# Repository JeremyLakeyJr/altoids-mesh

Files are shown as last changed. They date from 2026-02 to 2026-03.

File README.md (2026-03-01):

# Altoids Mesh Enclosure

A parametric, 3D-printable enclosure modeled after an Altoids tin, designed to house a complete Meshtastic communication node.

## Preview

### Assembled View
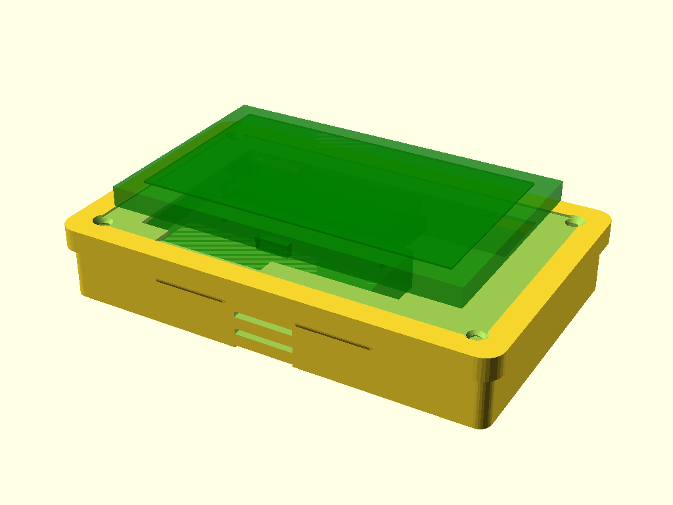
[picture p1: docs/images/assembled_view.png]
Assembled view of the Altoids Mesh enclosure


### Exploded View
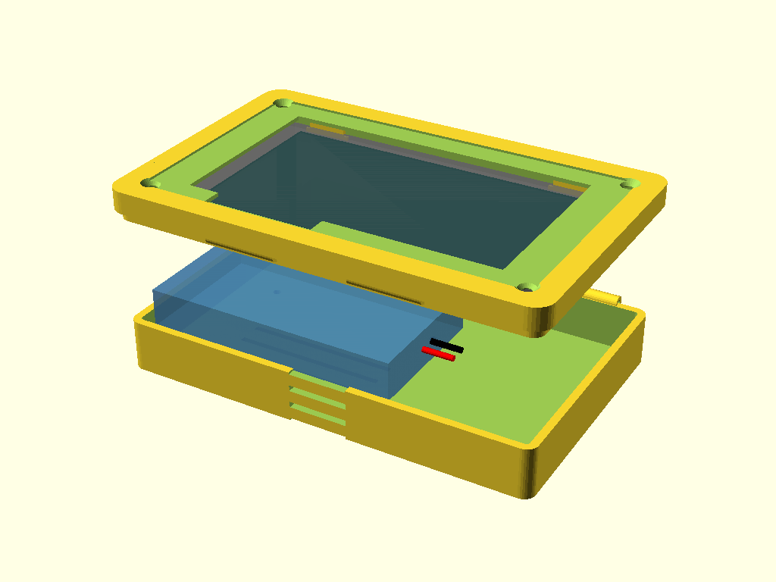
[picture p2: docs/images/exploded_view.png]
Exploded view showing all components separated


### Print Layout
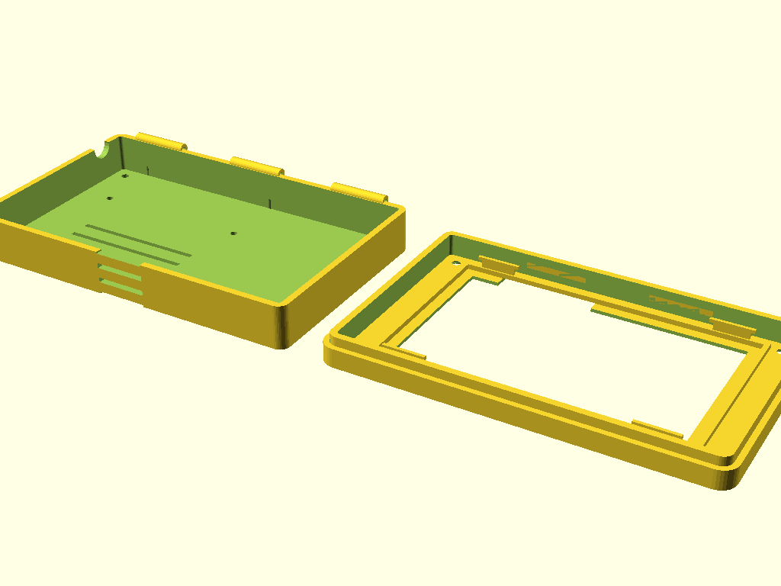
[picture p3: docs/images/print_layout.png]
Print layout with parts arranged for 3D printing


## Components

| Component | Dimensions (mm) | Description |
|---|---|---|
| Heltec V3 (WiFi LoRa 32) | 50.2 × 25.5 × 10.2 | ESP32-S3 + SX1262 LoRa module with OLED display (IPEX antenna) |
| Heltec V4 (WiFi LoRa 32) | 52 × 25 × 7 | Meshtastic-compatible LoRa module with OLED display |
| M5Stack CardKB Unit 1.1 | 88 × 54 × 5 | Credit-card-sized QWERTY keyboard (I2C) |
| MakerFocus 3.7V 3000mAh | 65 × 36 × 10 | Lithium polymer rechargeable battery |
| Standard paper clip | ~0.9 mm wire | Straightened — hinge pin for laptop-style lid |

## Enclosure Specifications

- **Style**: Altoids tin aesthetic — overlapping lid with embossed label panel
- **Wall thickness**: 2.0 mm case / 1.6 mm lid skirt (FDM-optimised)
- **Floor/ceiling**: 1.6 mm
- **Tolerance**: 0.3 mm general, 0.5 mm component fit
- **Closure**: Friction-fit overlapping lid with paper-clip barrel hinge
- **Hinge**: Barrel-type knuckle hinge along back edge — assembled with a straightened paper clip
- **Material**: PLA, PETG, or ABS recommended

## Key Design Features

- **Fully sealed when closed** — no through-holes, ports, or vents; all interfaces accessible when lid is hinged open
- **Altoids-style overlapping lid** — the lid skirt slides over the case walls, just like a real tin
- **Embossed label panel** — shallow recess on the lid top for branding or labelling
- **Front friction bump** — snap catch at the front for tool-free open/close
- **Paper-clip hinge** — no special hardware needed; a standard paper clip becomes the hinge pin
- **Battery compartment** with retention clips
- **Heltec V3 / V4 mounting** with M2 standoffs and PCB alignment guides
- **CardKB integration** in the lid with support ledges and retention clips
- **OLED display** visible when lid is open
- **Internal antenna housing** channel with retention clips — primary antenna solution (plastic doesn't block RF)
- **Corner screw bosses** for structural reinforcement

## File Structure

```
enclosure/
├── altoids_mesh_enclosure.scad   # Main assembly (open this first)
├── parameters.scad                # All configurable dimensions
├── components.scad                # Component models for visualisation
├── bottom_case.scad               # Bottom case (battery + Heltec)
└── top_lid.scad                   # Top lid (CardKB + display window)
docs/
├── assembly_guide.md              # Step-by-step assembly instructions
└── images/                        # Preview renders
stl/
└── .gitkeep                       # Export STL files here
```

## Quick Start

### Prerequisites

- [OpenSCAD](https://openscad.org/) (v2021.01 or later recommended)

### Viewing the Design

1. Open `enclosure/altoids_mesh_enclosure.scad` in OpenSCAD
   - **All `.scad` files in the `enclosure/` directory must remain together** for includes to resolve
2. Press **F5** for preview or **F6** for full render
3. Change the `render_mode` variable:
   - `0` = Assembled (closed) view
   - `1` = Exploded view (default)
   - `2` = Print layout (parts flat on build plate)
   - `3` = Laptop open (lid hinged open)

### Exporting STL Files

1. Open `enclosure/bottom_case.scad` → **F6** → Export as STL → save to `stl/bottom_case.stl`
2. Open `enclosure/top_lid.scad` → **F6** → Export as STL → save to `stl/top_lid.stl`

### Customisation

All dimensions are parametric. Edit `enclosure/parameters.scad` to adjust:

- **Board version** — set `board_version = 3` for Heltec V3 or `board_version = 4` for Heltec V4 (default)
- Component dimensions (if using different parts)
- Wall thickness and tolerances
- Friction fit / overlap clearance
- Hinge pin diameter (if using different wire)

## Printing Guidelines

| Setting | Recommended Value |
|---|---|
| Layer height | 0.2 mm |
| Infill | 20–30% |
| Walls/perimeters | 3 |
| Top/bottom layers | 4 |
| Supports | Not required (designed support-free) |
| Material | PLA (easiest), PETG (stronger), ABS (heat resistant) |
| Orientation | Print each part with the flat face down |

## Assembly

See [docs/assembly_guide.md](docs/assembly_guide.md) for detailed step-by-step instructions.

**Quick summary:** install battery → mount Heltec → route internal antenna → connect and seat CardKB in lid → straighten a paper clip → thread it through the hinge knuckles → close the lid.

## License

See [LICENSE](LICENSE) for details.

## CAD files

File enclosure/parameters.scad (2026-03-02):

// =============================================================================
// Altoids Mesh Enclosure — Parameters
// =============================================================================
// All configurable dimensions for the Altoids-style Meshtastic enclosure.
// Measurements in millimeters.  Edit values here to customise the design;
// every other file includes this one.
// =============================================================================

// =====================================================================
//  0. BOARD VERSION SELECTOR
// =====================================================================
// Set board_version to choose which Heltec board the enclosure targets:
//   3 = Heltec WiFi LoRa 32 V3  (ESP32-S3, SX1262, IPEX antenna)
//   4 = Heltec WiFi LoRa 32 V4  (default)
board_version = 4;

// =====================================================================
//  1. PRINTING TOLERANCES
// =====================================================================
tolerance       = 0.3;   // General FDM tolerance
fit_clearance   = 0.5;   // Clearance for component pockets
snap_clearance  = 0.4;   // Clearance for snap / friction fits

// =====================================================================
//  2. WALL & STRUCTURE
// =====================================================================
wall            = 2.0;   // Main wall thickness (bottom case)
floor_t         = 1.6;   // Floor / ceiling thickness
lid_wall        = 1.6;   // Lid skirt wall thickness
lid_top_t       = 1.6;   // Lid top-surface thickness
corner_r        = 3.0;   // External corner radius (Altoids aesthetic)
fillet_r        = 1.0;   // Internal fillet radius for strength

// =====================================================================
//  3. COMPONENT DIMENSIONS — Heltec WiFi LoRa 32 (V3 / V4)
// =====================================================================
// V3: 50.2 × 25.5 × 10.2 mm, IPEX/U.FL antenna, ESP32-S3 + SX1262
// V4: 52   × 25   ×  7   mm, SMA antenna
heltec_len          = (board_version == 3) ? 50.2 : 52.0;
heltec_wid          = (board_version == 3) ? 25.5 : 25.0;
heltec_ht           = (board_version == 3) ? 10.2 :  7.0;
heltec_pcb_t        = 1.6;    // PCB thickness (same for both)
heltec_usbc_w       = 9.0;    // USB-C port width
heltec_usbc_h       = 3.5;    // USB-C port height
heltec_usbc_off_y   = (board_version == 3) ? 12.75 : 12.5;
heltec_oled_w       = 27.0;   // OLED display window width  (0.96" on both)
heltec_oled_h       = 11.0;   // OLED display window height
heltec_oled_off_x   = (board_version == 3) ? 10.0 : 12.0;
heltec_oled_off_y   = 7.0;    // OLED offset from PCB edge (Y)
heltec_antenna_dia  = (board_version == 3) ?  3.0 :  6.5;
heltec_mount_hole   = 2.2;    // Mounting-hole diameter (M2 screw)
heltec_standoff     = 3.0;    // Stand-off height under PCB

// =====================================================================
//  4. COMPONENT DIMENSIONS — M5Stack CardKB Unit 1.1
// =====================================================================
cardkb_len       = 88.0;  // Length (X)
cardkb_wid       = 54.0;  // Width  (Y)
cardkb_ht        = 5.0;   // Thickness (Z)
cardkb_cable_w   = 8.0;   // Grove / I²C cable connector width
cardkb_cable_off = 44.0;  // Cable connector offset from edge

// =====================================================================
//  5. COMPONENT DIMENSIONS — MakerFocus 3.7 V 3000 mAh Battery
// =====================================================================
batt_len         = 65.0;  // Length (X)
batt_wid         = 36.0;  // Width  (Y)
batt_ht          = 10.0;  // Height (Z)
batt_wire_clr    = 8.0;   // Space for battery wires / JST connector

// =====================================================================
//  6. ENCLOSURE INTERNAL DIMENSIONS  (derived)
// =====================================================================
// Battery + Heltec overlap ~15 mm along X (staggered layout).
comp_overlap = 15;

int_len = max(cardkb_len,
              batt_len + heltec_len - comp_overlap)
          + fit_clearance * 2;                        // ≈ 92 mm

int_wid = max(cardkb_wid,
              batt_wid + heltec_wid + fit_clearance)
          + fit_clearance * 2;                        // ≈ 63 mm

case_int_depth = max(batt_ht,
                     heltec_ht + heltec_standoff)
                 + fit_clearance + 1.0;               // ≈ 14 mm

lid_int_depth = cardkb_ht + fit_clearance + 1.0;     // ≈  7 mm

// =====================================================================
//  7. ENCLOSURE EXTERNAL DIMENSIONS  (derived)
// =====================================================================
// Bottom case outer shell
case_ext_len   = int_len + wall * 2;
case_ext_wid   = int_wid + wall * 2;
case_ext_depth = case_int_depth + floor_t;

// Lid outer shell — slightly larger so the skirt overlaps the case walls
lid_overlap      = 4.0;       // How far the lid skirt extends down over case
lid_ext_len      = case_ext_len + (lid_wall + snap_clearance) * 2;
lid_ext_wid      = case_ext_wid + (lid_wall + snap_clearance) * 2;
lid_ext_depth    = lid_int_depth + lid_top_t;

total_height = case_ext_depth + lid_ext_depth;

// =====================================================================
//  8. ALTOIDS-STYLE LID OVERLAP / FRICTION FIT
// =====================================================================
// The lid skirt slides over the top of the case walls, just like a real
// Altoids tin.  A small bump on the front of the skirt provides a
// friction catch.
friction_bump_w = 12.0;   // Width of the front-edge friction bump
friction_bump_h = 0.5;    // Height (radial protrusion) of the bump

// =====================================================================
//  9. VENTILATION
// =====================================================================
vent_len     = 15.0;  // Slot length
vent_w       = 1.5;   // Slot width
vent_space   = 3.0;   // Centre-to-centre spacing
vent_count   = 4;     // Slots per group

// =====================================================================
// 10. SCREW MOUNTS  (optional alternative to snap-fit)
// =====================================================================
screw_d      = 2.5;   // M2.5 hole diameter
screw_boss_d = 6.0;   // Boss outer diameter

// =====================================================================
// 11. PORT CUTOUTS  (derived)
// =====================================================================
usbc_cut_w     = heltec_usbc_w + tolerance * 2;
usbc_cut_h     = heltec_usbc_h + tolerance * 2;
antenna_cut_d  = heltec_antenna_dia + tolerance * 2;
wire_slot_w    = 10.0;    // Wire routing slot width
wire_slot_h    = 5.0;     // Wire routing slot height

// =====================================================================
// 12. INTERNAL ANTENNA HOUSING
// =====================================================================
// Channel along the front wall for an internal LoRa wire antenna.
// Plastic does not block RF, so no external SMA antenna is required.
ant_len       = 82.0;  // Quarter-wave for 915 MHz  (c/f/4 ≈ 82 mm)
ant_chan_w    = 2.0;    // Channel width
ant_chan_d    = 3.5;    // Rail height above floor
ant_rail_t   = 0.8;    // Retaining-rail thickness
ant_clip_n   = 3;      // Number of retention clips
ant_clip_w   = 4.0;    // Width of each clip
ant_clip_ins = 0.3;    // Clip inset for snug fit

// Position (front wall interior, centred along X)
ant_pos_x = (int_len - ant_len) / 2;
ant_pos_y = 0;

// =====================================================================
// 13. COMPONENT POSITIONING  (relative to case interior origin)
// =====================================================================
batt_pos_x = fit_clearance + 2.0;
batt_pos_y = fit_clearance + 2.0;
batt_pos_z = floor_t;

heltec_pos_x = batt_pos_x + 5.0;
heltec_pos_y = batt_pos_y + batt_wid + fit_clearance + 2.0;
heltec_pos_z = floor_t + heltec_standoff;

cardkb_pos_x = (int_len - cardkb_len) / 2;
cardkb_pos_y = (int_wid - cardkb_wid) / 2;

// =====================================================================
// 14. DISPLAY WINDOW  (above Heltec OLED in assembled view)
// =====================================================================
oled_win_x = heltec_pos_x + heltec_oled_off_x;
oled_win_y = heltec_pos_y + heltec_oled_off_y;
oled_win_w = heltec_oled_w + 1.0;
oled_win_h = heltec_oled_h + 1.0;
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

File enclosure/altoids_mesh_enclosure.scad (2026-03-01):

// =============================================================================
// Altoids Mesh Enclosure — Main Assembly
// =============================================================================
// Open this file in OpenSCAD to see the complete enclosure with components.
//
// Render modes (change render_mode below):
//   0 = Assembled (closed)
//   1 = Exploded view   (default)
//   2 = Print layout     (parts flat on build plate)
//   3 = Laptop open      (lid hinged open)
//
// Companion files (must be in the same directory):
//   parameters.scad   — shared dimensions / configuration
//   bottom_case.scad  — bottom half of the enclosure
//   top_lid.scad      — top lid (Altoids-style overlapping)
//   components.scad   — visual component models
// =============================================================================

include <parameters.scad>

// =====================================================================
//  Render Settings
// =====================================================================
render_mode     = 1;      // 0 assembled · 1 exploded · 2 print · 3 laptop
show_components = true;   // toggle component ghost models
explode_dist    = 30;     // separation for exploded view  (mm)
laptop_angle    = 110;    // lid opening angle for laptop view (°)

// =====================================================================
//  Import Part Modules
// =====================================================================
use <bottom_case.scad>
use <top_lid.scad>
use <components.scad>

// Offset from case origin to lid origin (the lid is wider by lid_off
// on each side so that the skirt overlaps the case walls).
lid_off = lid_wall + snap_clearance;

// =====================================================================
//  Assembly Views
// =====================================================================

// ----- Closed assembly -----------------------------------------------
module assembly_view() {
    // Bottom case
    bottom_case();

    // Top lid — flipped and placed on top, offset inward by lid_off
    translate([-lid_off, -lid_off,
               case_ext_depth + lid_top_t + lid_overlap])
        rotate([180, 0, 0])
            translate([0, -lid_ext_wid, 0])
                top_lid();

    if (show_components)
        color("green", 0.5)
            translate([wall, wall, 0])
                component_assembly();
}

// ----- Exploded view -------------------------------------------------
module exploded_view() {
    bottom_case();

    translate([-lid_off, -lid_off,
               case_ext_depth + explode_dist
                   + lid_top_t + lid_overlap])
        rotate([180, 0, 0])
            translate([0, -lid_ext_wid, 0])
                top_lid();

    if (show_components)
        translate([wall, wall, 0]) {
            translate([batt_pos_x, batt_pos_y,
                       batt_pos_z + explode_dist * 0.3])
                battery_3000mah();
            translate([heltec_pos_x, heltec_pos_y,
                       heltec_pos_z + explode_dist * 0.5])
                heltec_v4();
            translate([cardkb_pos_x, cardkb_pos_y,
                       case_ext_depth + explode_dist * 0.7 + 5])
                cardkb_unit();
            translate([ant_pos_x, ant_pos_y,
                       floor_t + explode_dist * 0.2])
                internal_antenna();
        }
}

// ----- Print layout --------------------------------------------------
module print_layout() {
    bottom_case();
    translate([case_ext_len + 10, 0, 0])
        top_lid();
}

// ----- Laptop (lid hinged open) --------------------------------------
module laptop_view() {
    bottom_case();

    // Pivot around the hinge axis at the back edge of the case
    translate([0, case_ext_wid, case_ext_depth])
        rotate([-laptop_angle, 0, 0])
            translate([0, -case_ext_wid, -case_ext_depth])
                // Closed-lid position
                translate([-lid_off, -lid_off,
                           case_ext_depth + lid_top_t + lid_overlap])
                    rotate([180, 0, 0])
                        translate([0, -lid_ext_wid, 0])
                            top_lid();

    if (show_components)
        color("green", 0.5)
            translate([wall, wall, 0])
                component_assembly();
}

// =====================================================================
//  Render Selected Mode
// =====================================================================
if      (render_mode == 0) assembly_view();
else if (render_mode == 1) exploded_view();
else if (render_mode == 2) print_layout();
else if (render_mode == 3) laptop_view();

// =====================================================================
//  Console Dimension Summary
// =====================================================================
echo(str("=== Altoids Mesh Enclosure ==="));
echo(str("Board      : Heltec WiFi LoRa 32 V", board_version));
echo(str("Case outer : ", case_ext_len, " × ", case_ext_wid,
         " × ", case_ext_depth, " mm"));
echo(str("Lid  outer : ", lid_ext_len,  " × ", lid_ext_wid,
         " × ", lid_ext_depth,  " mm"));
echo(str("Total height (closed): ", total_height, " mm"));
echo(str("Hinge pin  : paper clip  ø", hinge_pin_d, " mm"));
echo(str("(Real Altoids tin ≈ 95.5 × 60 × 21.5 mm for reference)"));

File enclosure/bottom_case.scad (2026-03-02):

// =============================================================================
// Altoids Mesh Enclosure — Bottom Case
// =============================================================================
// Shallow tray (like the bottom of a real Altoids tin) that holds the
// battery, Heltec board (V3 or V4), and internal antenna.  The lid skirt
// slides over the top of these walls.
//
// Features:  battery compartment · Heltec mounting standoffs · hinge
//            knuckles · internal antenna channel · corner screw bosses
//            USB-C port cutout · SMA antenna passthrough · wire routing
// =============================================================================

include <parameters.scad>

// =========================================================================
//  Helper Modules
// =========================================================================

// Rounded rectangle (origin at corner, Z-up)
module rrect(size, r) {
    hull() {
        for (dx = [r, size[0] - r], dy = [r, size[1] - r])
            translate([dx, dy, 0])
                cylinder(r = r, h = size[2], $fn = 36);
    }
}

// Array of ventilation slots centred at origin
module vent_slots(n, len, w, spacing) {
    tw = n * w + (n - 1) * spacing;
    for (i = [0 : n - 1])
        translate([0, i * (w + spacing) - tw / 2, 0])
            cube([len, w, wall * 3], center = true);
}

// ----- Battery Retainer Clip -------------------------------------------------
module battery_retainer() {
    clip_h  = batt_ht * 0.6;
    clip_t  = 1.5;
    clip_oh = 2.0;
    cube([clip_t, batt_wid + fit_clearance * 2, clip_h]);
    translate([0, 0, clip_h])
        cube([clip_oh, batt_wid + fit_clearance * 2, clip_t]);
}

// ----- Hinge Knuckle (case side) ---------------------------------------------
// Barrel with paper-clip pin hole + support arm toward case interior.
module case_hinge_knuckle(x_pos, klen) {
    barrel_r = hinge_barrel_d / 2;
    translate([x_pos, case_ext_wid, case_ext_depth]) {
        difference() {
            union() {
                // Barrel along X
                rotate([0, 90, 0])
                    cylinder(d = hinge_barrel_d, h = klen, $fn = 24);
                // Arm connecting barrel to case wall (extends -Y, -Z)
                translate([0, -hinge_arm_t, -barrel_r])
                    cube([klen, hinge_arm_t, barrel_r]);
            }
            // Pin hole (paper-clip clearance)
            translate([-0.1, 0, 0])
                rotate([0, 90, 0])
                    cylinder(d = hinge_pin_d + tolerance * 2,
                             h = klen + 0.2, $fn = 24);
        }
    }
}

// =========================================================================
//  Main Bottom Case
// =========================================================================
module bottom_case() {
    difference() {
        union() {
            // ----------------------------------------------------------
            //  Outer shell
            // ----------------------------------------------------------
            rrect([case_ext_len, case_ext_wid, case_ext_depth], corner_r);

            // ----------------------------------------------------------
            //  Battery compartment rails
            // ----------------------------------------------------------
            translate([wall + batt_pos_x - 1.5,
                       wall + batt_pos_y - 1.5, 0]) {
                // Left rail
                cube([batt_len + batt_wire_clr + 3, 1.5,
                      floor_t + batt_ht * 0.7]);
                // Right rail
                translate([0, batt_wid + fit_clearance * 2 + 1.5, 0])
                    cube([batt_len + batt_wire_clr + 3, 1.5,
                          floor_t + batt_ht * 0.7]);
                // Back wall
                translate([-0.5, 0, 0])
                    cube([2.0, batt_wid + fit_clearance * 2 + 3,
                          floor_t + batt_ht * 0.7]);
            }

            // Battery retainer clip (front)
            translate([wall + batt_pos_x + batt_len + batt_wire_clr + 1,
                       wall + batt_pos_y - 1.5, 0]) {
                ch = batt_ht * 0.6;
                ct = 1.5;
                co = 2.0;
                cube([ct, batt_wid + fit_clearance * 2,
                      floor_t + ch]);
                translate([0, 0, floor_t + ch])
                    cube([co, batt_wid + fit_clearance * 2, ct]);
            }

            // ----------------------------------------------------------
            //  Heltec V4 mounting standoffs
            // ----------------------------------------------------------
            mount_pts = [
                [2.5, 2.5],
                [heltec_len - 2.5, 2.5],
                [2.5, heltec_wid - 2.5],
                [heltec_len - 2.5, heltec_wid - 2.5]
            ];
            for (p = mount_pts)
                translate([wall + heltec_pos_x + p[0],
                           wall + heltec_pos_y + p[1], 0])
                    cylinder(d = screw_boss_d - 1,
                             h = floor_t + heltec_standoff, $fn = 24);

            // ----------------------------------------------------------
            //  Corner screw bosses
            // ----------------------------------------------------------
            screw_pts = [
                [wall + 4, wall + 4],
                [case_ext_len - wall - 4, wall + 4],
                [wall + 4, case_ext_wid - wall - 4],
                [case_ext_len - wall - 4, case_ext_wid - wall - 4]
            ];
            for (p = screw_pts)
                translate([p[0], p[1], 0])
                    cylinder(d = screw_boss_d,
                             h = case_ext_depth, $fn = 24);

            // ----------------------------------------------------------
            //  Cable channel (between battery and Heltec)
            // ----------------------------------------------------------
            translate([wall + batt_pos_x + batt_len,
                       wall + batt_pos_y + batt_wid - 2, 0])
                cube([3,
                      heltec_pos_y - batt_pos_y - batt_wid + 4,
                      floor_t + 2]);

            // ----------------------------------------------------------
            //  Hinge knuckles  (case gets knuckles 0, 2, 4)
            // ----------------------------------------------------------
            for (i = [0, 2, 4]) {
                xp = hinge_margin + i * (hinge_knuckle_l + hinge_gap);
                case_hinge_knuckle(xp, hinge_knuckle_l);
            }

            // ----------------------------------------------------------
            //  Internal antenna housing channel
            // ----------------------------------------------------------
            translate([wall + ant_pos_x, wall, 0]) {
                // Retaining rail
                translate([0, ant_chan_w, 0])
                    cube([ant_len, ant_rail_t,
                          floor_t + ant_chan_d]);
                // End walls
                cube([ant_rail_t,
                      ant_chan_w + ant_rail_t,
                      floor_t + ant_chan_d]);
                translate([ant_len - ant_rail_t, 0, 0])
                    cube([ant_rail_t,
                          ant_chan_w + ant_rail_t,
                          floor_t + ant_chan_d]);
                // Retention clips
                for (i = [0 : ant_clip_n - 1]) {
                    cx = ant_len * (i + 1) / (ant_clip_n + 1)
                         - ant_clip_w / 2;
                    translate([cx, ant_rail_t + ant_clip_ins,
                               floor_t + ant_chan_d])
                        cube([ant_clip_w, ant_chan_w, ant_rail_t]);
                }
            }
        }

        // ==============================================================
        //  Subtractive features
        // ==============================================================

        // Hollow interior
        translate([wall, wall, floor_t])
            rrect([int_len, int_wid, case_int_depth + 1],
                  corner_r - wall);

        // USB-C port cutout (through +X end wall)
        translate([case_ext_len - wall - 0.1,
                   wall + heltec_pos_y + heltec_usbc_off_y
                       - usbc_cut_w / 2,
                   heltec_pos_z + heltec_pcb_t - tolerance])
            cube([wall + 0.2, usbc_cut_w, usbc_cut_h]);

        // SMA antenna passthrough (through −X end wall)
        translate([-0.1,
                   wall + heltec_pos_y + heltec_wid / 2,
                   heltec_pos_z + heltec_ht / 2])
            rotate([0, 90, 0])
                cylinder(d = antenna_cut_d, h = wall + 0.2, $fn = 24);
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

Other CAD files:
enclosure/components.scad
enclosure/top_lid.scad

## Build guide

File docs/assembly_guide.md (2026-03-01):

# Assembly Guide

Step-by-step instructions for assembling the Altoids Mesh enclosure.

## Required Tools

- Small Phillips screwdriver (if using screw mounting)
- Flush cutters or craft knife (for support cleanup if needed)
- Needle-nose pliers (for straightening the paper clip)
- Soldering iron (if connecting battery directly)

## Required Hardware

| Item | Quantity | Notes |
|---|---|---|
| Heltec V3 or V4 module | 1 | With OLED display (set `board_version` in parameters.scad to match) |
| M5Stack CardKB Unit 1.1 | 1 | With Grove/I2C cable |
| MakerFocus 3.7V 3000mAh battery | 1 | With JST connector |
| M2 × 5mm screws | 4 | For Heltec mounting (recommended for sealed use) |
| Standard paper clip | 1 | Straightened — used as the hinge pin (~0.9 mm wire) |
| SMA pigtail + wire antenna | 1 | For internal antenna housing |

## Pre-Assembly Checks

1. **Print quality**: Inspect both printed parts for warping, stringing, or layer adhesion issues
2. **Fit test**: Slide the lid skirt over the bottom case walls to verify the overlap fits
3. **Clean surfaces**: Ensure mating surfaces and interior features are clean and free of stringing or support material
4. **Component inspection**: Verify all electronic components are functioning before installation

## Assembly Steps

### Step 1: Install the Battery

1. Place the MakerFocus battery into the battery compartment in the bottom case
2. Orient the battery with wires facing toward the centre of the case
3. Route the JST connector wire along the cable channel toward the Heltec mounting area
4. Verify the battery retention clip holds the battery securely
5. Ensure the battery sits flat and does not obstruct the Heltec mounting standoffs

### Step 2: Mount the Heltec Board

1. Connect the battery JST connector to the Heltec board's battery input
2. Lower the Heltec board onto the four mounting standoffs
3. Secure with M2 screws through the mounting holes (recommended for sealed use)
4. Verify the OLED display faces upward and is visible when the lid is open

### Step 3: Install Internal Antenna

The sealed design uses an internal wire antenna:

1. Connect an SMA pigtail cable (V4) or IPEX/U.FL pigtail (V3) to the Heltec antenna connector
2. Route the wire antenna along the antenna housing channel on the front wall of the case
3. Tuck the wire under the retention clips to secure it in the channel
4. Ensure the antenna wire is fully seated in the channel and does not interfere with other components

> **Note:** The sealed enclosure has no external antenna port, so an internal wire
> antenna is required. The plastic enclosure does not block RF signals, so an
> internal wire antenna provides comparable performance to an external antenna
> while keeping the enclosure sealed and compact. A quarter-wave wire antenna
> (~82 mm for 915 MHz) fits the housing channel.

### Step 4: Connect the CardKB

1. Connect the Grove/I2C cable to the Heltec board's I2C port
2. Connect the other end to the CardKB Unit 1.1

### Step 5: Install CardKB in Lid

1. With the lid interior facing up, place the CardKB onto the support ledges
2. Press down gently until the retention clips snap over the edges
3. Verify the keyboard is seated securely
4. Ensure the cable is routed cleanly

### Step 6: Prepare the Hinge Pin

1. Take a standard paper clip and straighten it completely using needle-nose pliers
2. The straightened wire should be approximately 80–90 mm long (trim if needed)
3. Optionally bend a tiny 1–2 mm 90° hook at one end to act as a retainer

### Step 7: Install the Hinge Pin

1. Align the bottom case and top lid so the hinge knuckles on the back edge interleave
   - The bottom case has three knuckle barrels (positions 0, 2, 4)
   - The top lid has two knuckle barrels (positions 1, 3)
2. Slide the straightened paper clip through all five knuckle barrels from one side
3. Trim the wire flush with the outer knuckles, or bend the last 1–2 mm at each end to prevent it sliding out
4. Verify the lid swings open and closed smoothly around the hinge

> **Tip:** A small drop of super glue on one bent end permanently secures the
> pin while still allowing removal from the other side if needed.

### Step 8: Close the Enclosure

1. Carefully fold excess cable into the case interior
2. Swing the lid closed — the skirt should slide over the case walls
3. Press gently until the friction bump at the front clicks into place
4. Verify a firm, even closure with no gaps

### Step 9: Final Checks

1. **USB-C access**: Verify a USB-C cable can be connected when the lid is open
2. **Antenna**: Confirm the internal antenna wire is secure in the housing channel
3. **Display visibility**: Confirm the OLED display is visible when the lid is open
4. **Keyboard function**: Test all CardKB keys with the lid open
5. **Hinge action**: Open and close the lid several times to verify smooth operation
6. **Power on**: Turn on the Heltec board and verify Meshtastic boots correctly

## Disassembly

1. Gently pull the front of the lid upward to release the friction bump
2. Swing the lid open on its hinge
3. Disconnect cables before fully separating lid from base
4. To remove the hinge, straighten any bent ends and slide the paper clip out

## Troubleshooting

| Issue | Solution |
|---|---|
| Lid too tight | Sand the skirt interior lightly or increase `snap_clearance` in parameters.scad |
| Lid too loose | Decrease `snap_clearance` or increase `friction_bump_h` in parameters.scad |
| Battery rattles | Add foam tape padding or decrease battery compartment tolerances |
| Hinge too stiff/loose | Adjust `hinge_gap` in parameters.scad; sand barrel interiors if needed |
| Hinge pin slides out | Bend the last 1–2 mm of the wire at each end |
| Paper clip too thick | Use a smaller paper clip or lightly sand the wire; standard clips are ~0.9 mm |

> **Note:** The sealed design has no ventilation openings. If heat is a concern
> during extended use, consider printing in PETG or ABS for better heat
> resistance, or briefly open the lid to allow airflow.

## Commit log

2026-02-24 Add parametric OpenSCAD enclosure design with validated geometry
    [altoids_mesh_enclosure.scad, bottom_case.scad, components.scad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]
2026-02-24 Address code review: rename variables and document magic number
    [bottom_case.scad, parameters.scad]
2026-02-24 Add internal antenna housing channel and fix include documentation
    - Add antenna housing parameters (length, width, depth, clips) to parameters.scad
    - Add antenna channel geometry with retaining rail and clips to bottom_case.scad
    - Add internal_antenna visual model to components.scad
    - Add IMPORTANT note in main assembly file about companion file requirements
    - Update README.md with internal antenna feature and file co-location note
    - Update assembly_guide.md with internal antenna installation steps
    [altoids_mesh_enclosure.scad, bottom_case.scad, components.scad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]
2026-02-24 Address code review: document frequency band, extract clip offset parameter
    [bottom_case.scad, parameters.scad]
2026-02-24 Add model screenshots to README (assembled, exploded, and print layout views)
2026-02-24 Add laptop-style barrel hinges along back edge with new render mode
    [altoids_mesh_enclosure.scad, bottom_case.scad, parameters.scad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]
2026-02-24 Fix documentation: add units to hinge pin length, correct knuckle position numbering
2026-02-24 Redesign enclosure: Altoids-style overlapping lid, paper-clip hinge, clean code organization
    [altoids_mesh_enclosure.scad, bottom_case.scad, components.scad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]
2026-02-24 docs: update assembly guide and README for sealed enclosure design
    Remove references to USB-C port cutout, SMA antenna port, charging LED
    window, ventilation slots, corner screw holes, and lid keyboard/display
    openings. The enclosure is now fully sealed when closed — all interfaces
    (USB-C, OLED, keyboard) are accessible only when the lid is hinged open.
    Internal antenna is the sole antenna option.
    [bottom_case.scad, top_lid.scad]
2026-02-24 Address code review: clarify blind hole depth, recommend M2 screws for sealed use
    [bottom_case.scad]
2026-03-01 Add Heltec V3 board support via board_version parameter
    - Add board_version selector (3 or 4) to parameters.scad with
    conditional Heltec dimensions (PCB size, height, antenna type)
    - Add heltec_v3() visualization module to components.scad with
    IPEX/U.FL antenna connector
    - Update component_assembly() to select V3 or V4 based on board_version
    - Update console output to show selected board version
    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
    [altoids_mesh_enclosure.scad, bottom_case.scad, components.scad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]
2026-03-01 Revert "Fix enclosure geometry: hinge alignment, lid fit, CardKB pocket, add port cutouts"
2026-03-02 Fix enclosure geometry: hinge alignment, lid fit, CardKB pocket, add port cutouts
    - Fix lid hinge knuckle Y position (lid_off instead of lid_off+case_ext_wid)
    so barrels are coaxial with case barrels after assembly 180° flip
    - Fix lid hinge arm direction (+Y local instead of -Y) to connect
    toward lid body in assembled orientation
    - Increase snap_clearance from 0.2mm to 0.4mm for FDM tolerance
    - Reduce lid pocket wall outer dims from case_ext_len×case_ext_wid to
    (int_len-2*snap_clearance)×(int_wid-2*snap_clearance) so pocket
    nests inside case walls instead of stacking on top
    - Widen CardKB ledge clearances from 0.5mm to 1.0mm all around
    - Add USB-C port cutout through +X end wall
    -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
    [bottom_case.scad, parameters.scad, top_lid.scad]
2026-03-02 Move wire routing slot dimensions to parameters.scad
    [bottom_case.scad, parameters.scad]
